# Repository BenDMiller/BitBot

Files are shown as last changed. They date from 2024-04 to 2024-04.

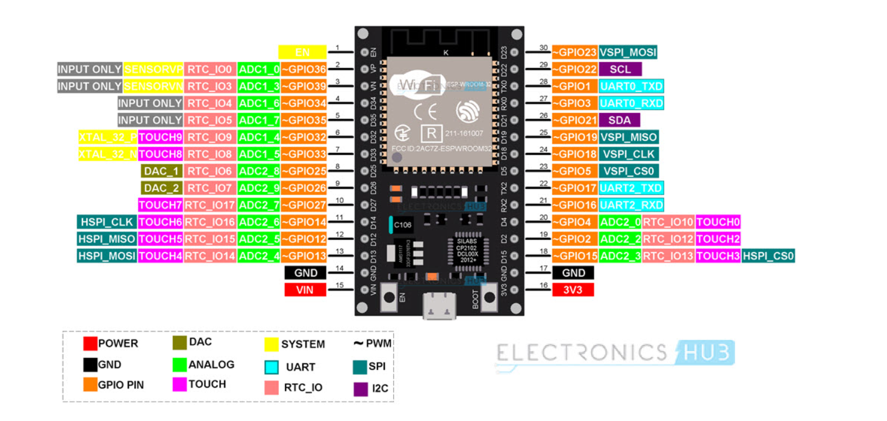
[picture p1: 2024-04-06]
Screenshot 2024-03-08 100537.png

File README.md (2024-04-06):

# Project Description

The BitBot is a simple robotics/embedded systems project that utilized motor control, an accelerometer, and a gyroscope to control the movement of the bot. There are two parts to the robot. There is the main robot body, and the glove controller.

The main body of the robot is a cylinder with two wheels on either side (hence the name, BitBot). The body of the bot, as well as the wheels, were 3D modelled and printed using the Ender3 Creality 3D printer. The chassis for the controller of the bot was also 3D modeled and printed the same way. The controller is attached to a glove, and is used to determine the orientation of your hand in order to control the movement of the BitBot.

A video showing a basic overview can be found [here](https://youtu.be/PNtvKN4nRBg).

Included in the Github Repoistory, there is simple documentation that can be referenced for questions. If more is desired, reach out and that can be updated.

# DISCLAIMER

Not all of the wiring has been completely updated. The documentation provided has some schematics, and they mostly match the proper circuitry, but there are a few changes. If there is difficulty determining the proper circuit design using the designated parts provided, reach out and that can be updated.

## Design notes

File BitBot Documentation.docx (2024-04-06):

# BitBot Robotic Project

# Project Description

The BitBot is a simple robotics/embedded systems project that utilized motor control, an accelerometer, and a gyroscope to control the movement of the bot. There are two parts to the robot. There is the main robot body, and the glove controller.

The main body of the robot is a cylinder with two wheels on either side (hence the name, BitBot). The body of the bot, as well as the wheels, were 3D modelled and printed using the Ender3 Creality 3D printer. The chassis for the controller of the bot was also 3D modeled and printed the same way. The controller is attached to a glove, and is used to determine the orientation of your hand in order to control the movement of the BitBot.

## Parts

- ESP32 WROOM DevKit (https://www.amazon.com/dp/B08D5ZD528?psc=1&ref=ppx_yo2ov_dt_b_product_details) x2
- Wires
- Solder
- Miscellaneous 3D printed parts

Controller:

- MPU6050 3 Axis Accelerometer Gyroscope Module (https://www.amazon.com/dp/B00LP25V1A?ref=ppx_yo2ov_dt_b_product_details&th=1) x1
- Adafruit Powerboost 500c (https://www.amazon.com/dp/B00PY2YTVU?psc=1&ref=ppx_yo2ov_dt_b_product_details) x1
- Slide Switch (https://www.amazon.com/dp/B09R434VJQ?ref=ppx_yo2ov_dt_b_product_details&th=1) x1
- 3.7V 700mAh Lipo Battery (https://www.amazon.com/dp/B07TS8N25G?psc=1&ref=ppx_yo2ov_dt_b_product_details) x1
- Prototype PCB (4cmx6cm) (https://www.amazon.com/dp/B07NM68FXK?psc=1&ref=ppx_yo2ov_dt_b_product_details) x1
- Glove (https://www.amazon.com/dp/B07HG6VMQ9?ref=ppx_yo2ov_dt_b_product_details&th=1&psc=1) x1

Bot:

- 12V 1000RPM DC Motor (https://www.amazon.com/dp/B0745YDSJS?psc=1&ref=ppx_yo2ov_dt_b_product_details) x2
- L298N Motor Driver (https://www.amazon.com/dp/B07WS89781?ref=ppx_yo2ov_dt_b_product_details&th=1) x1
- Boat Rocker Switch (https://www.amazon.com/dp/B0BCJXJZZ7?ref=ppx_yo2ov_dt_b_product_details&th=1) x1
- 12V 2400mAh Li-Ion Battery (https://www.amazon.com/dp/B0C241NS29?ref=ppx_yo2ov_dt_b_product_details&th=1) x1
- Rubber strips for wheel treads (https://www.amazon.com/dp/B08Y7NJJ5C?ref=ppx_yo2ov_dt_b_product_details&th=1)
- M3x0.5 Bolts x6

# Basic Design

The BitBot consists of the main body, as well as the controller. Both require housing and circuitry. Diagrams for both of these can be found below.

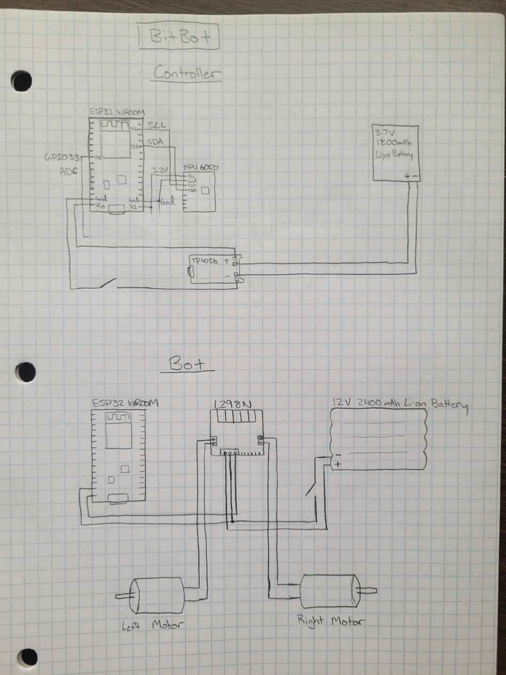
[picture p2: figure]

Figure 1: Basic Circuit Diagrams (control wires for bot not shown)

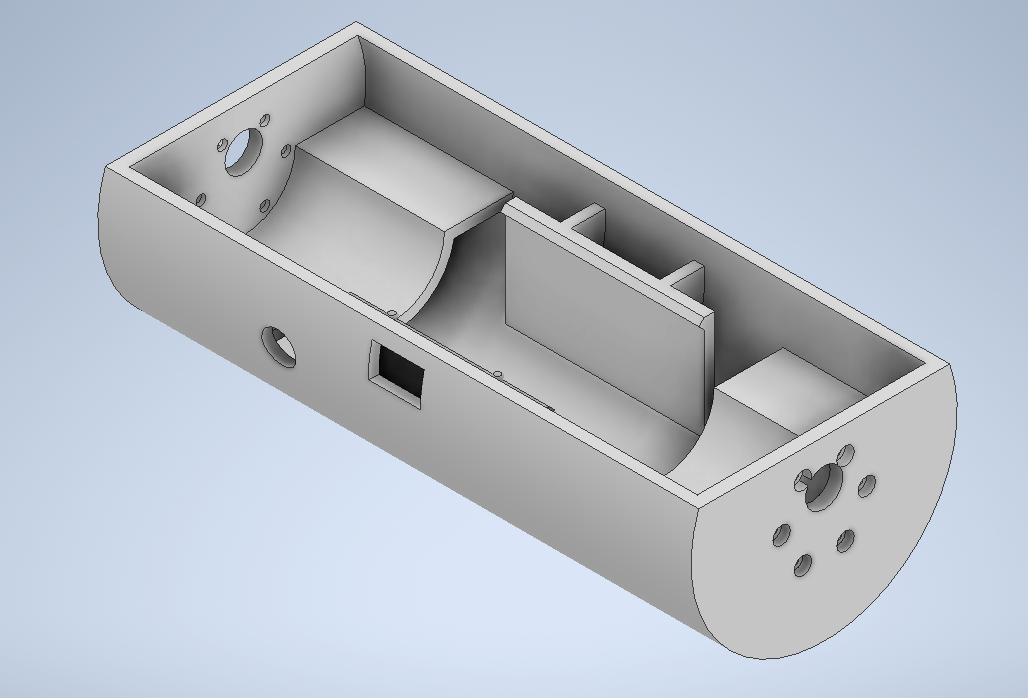
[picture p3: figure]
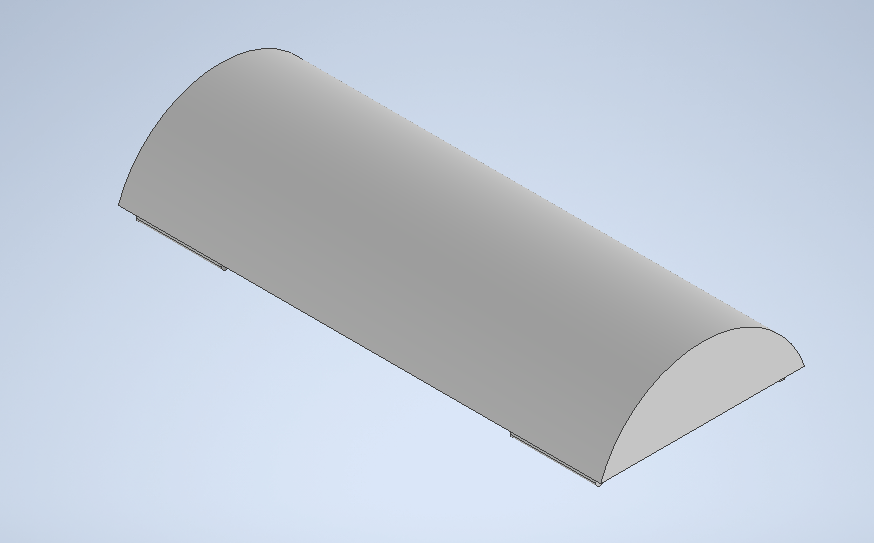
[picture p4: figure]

Figure 2: BitBot Bottom Body Figure 3: BitBot Top Body

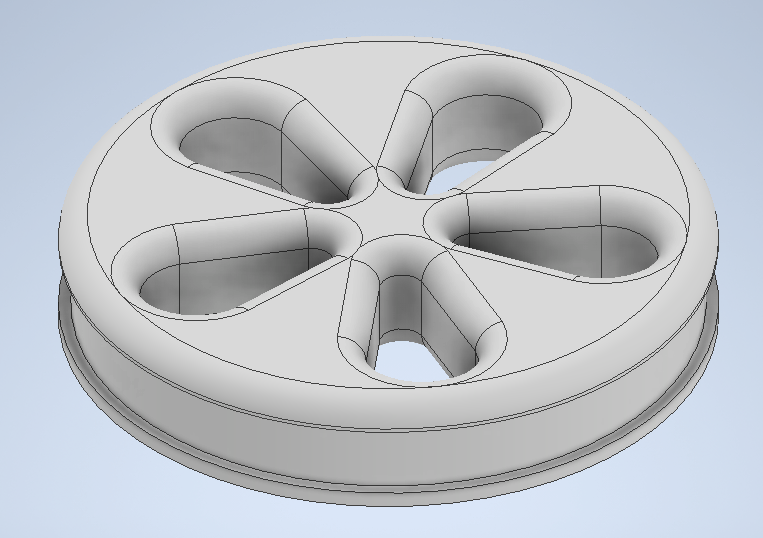
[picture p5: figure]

Figure 4: BitBot Wheel

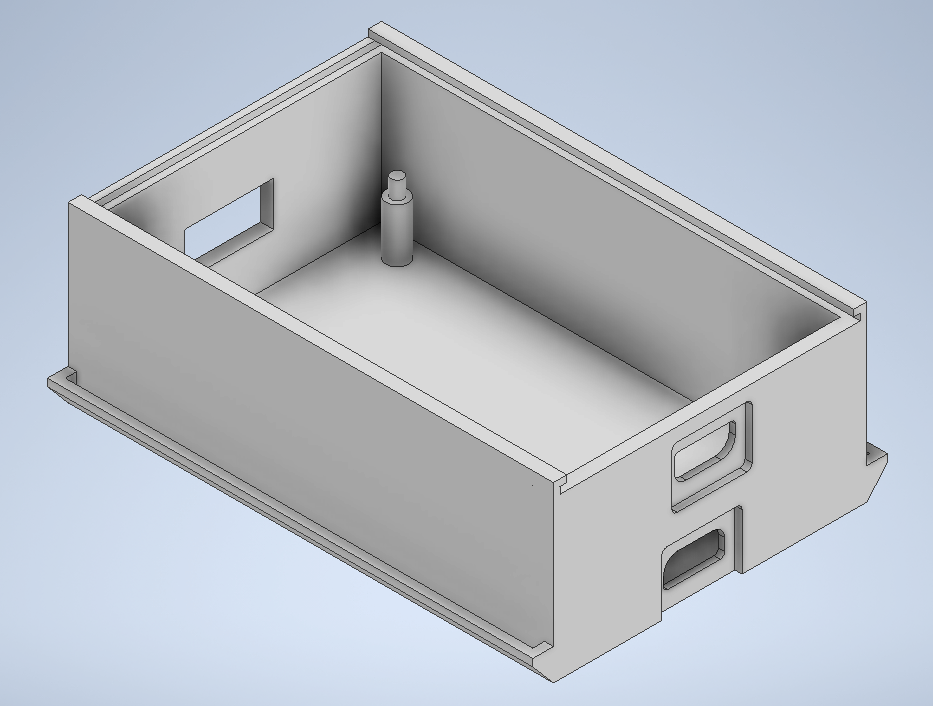
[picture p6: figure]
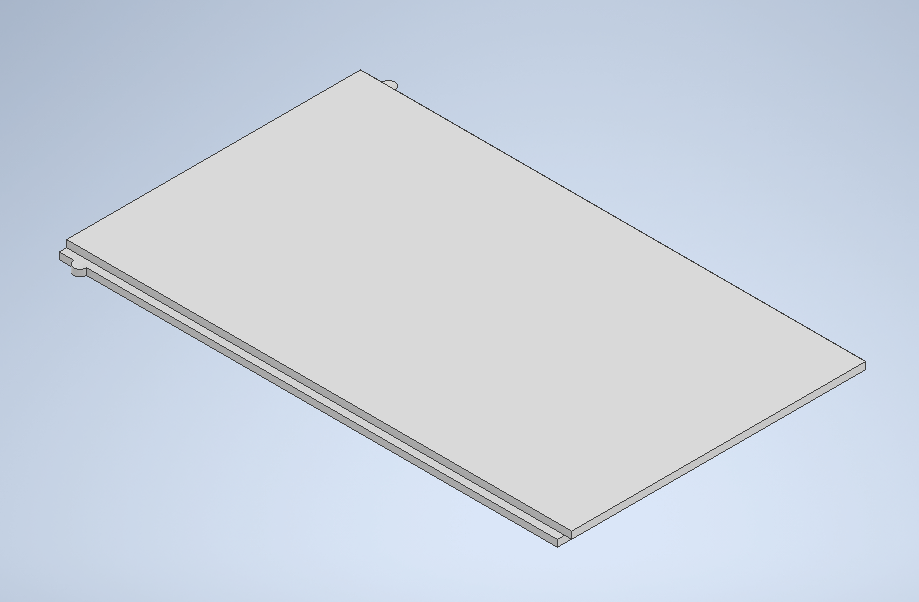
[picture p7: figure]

Figure 5: Controller Chassis Figure 6: Controller Lid

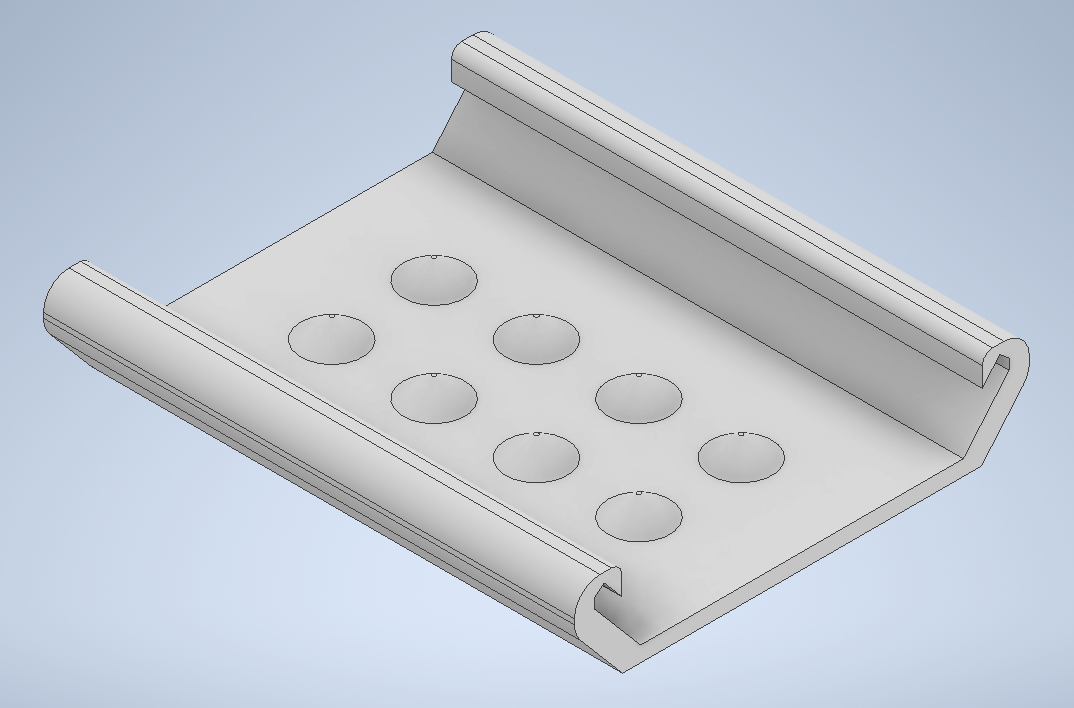
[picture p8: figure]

Figure 7: Controller Glove Clamp

The assembly is simple. The top of the BitBot body snaps into place on the BitBot Bottom Body. It may take some effort to get it in place, but it will go. Then, two wheels are used and attached to the shafts of each of the motors. The motors are attached to the body of the bot using the M3 bolts. After the parts are all put into the body, it will look like the image shown in Figure 8.

The controller is soldered together, and is placed into the Controller Chassis, which is used to house the controller’s system. The lid is slid over, and then that housing can be clamped to the archery glove, connecting the controller to the glove and allowing us to wear the glove and control the robot.

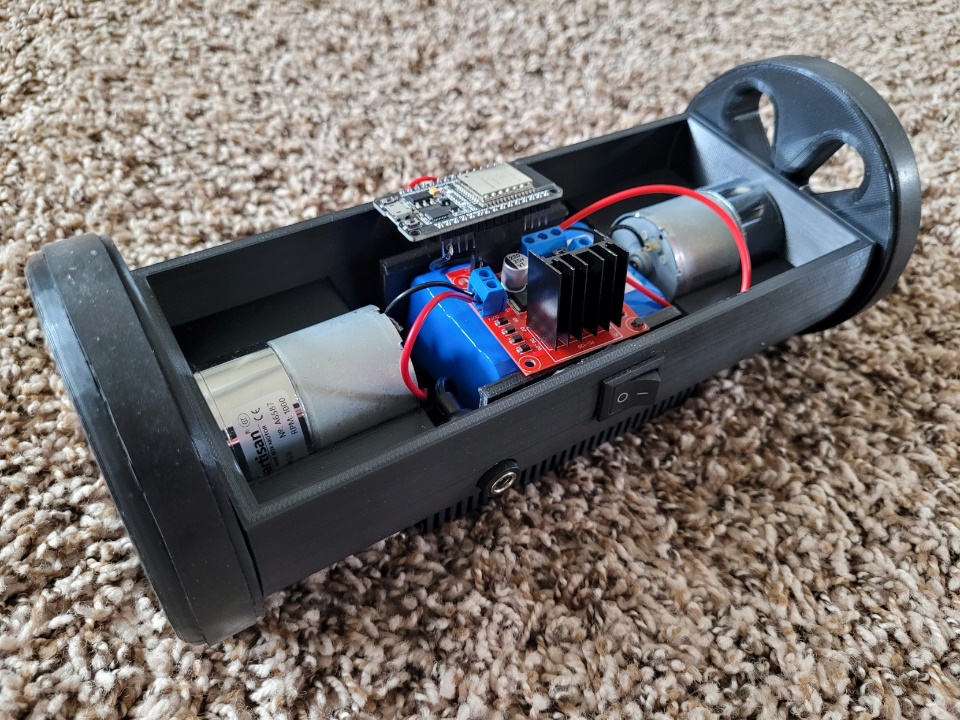
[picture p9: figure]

Figure 8: Completed BitBot without top

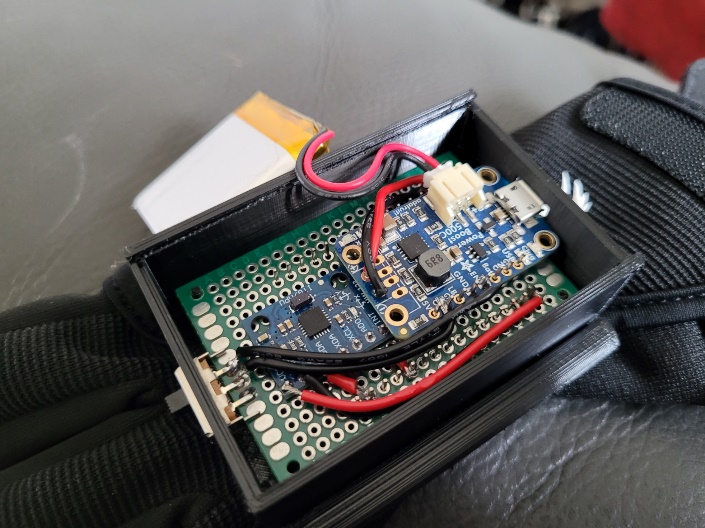
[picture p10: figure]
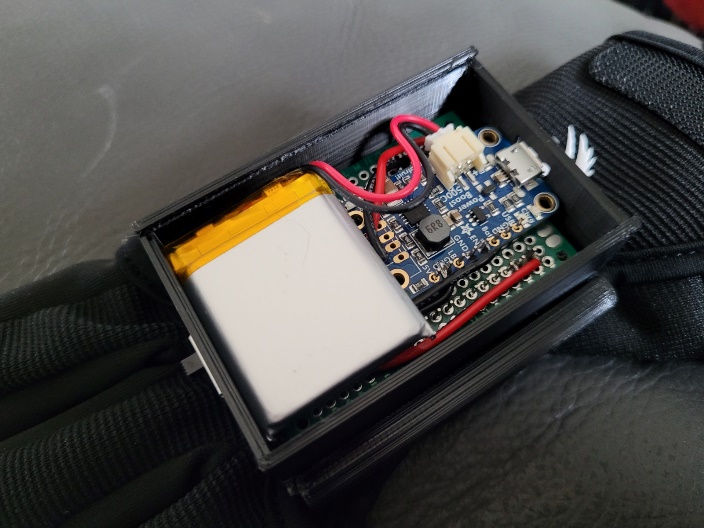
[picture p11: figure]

Figures 9 & 10: Controller circuit in housing, ESP32 soldered on bottom

The code for each of the boards can be uploaded either before or after the boards are soldered and put into their respective housings, though the actual bot’s ESP32 should be programmed before the top of the BitBot is put on. Then, both systems can be turned on, and after about 10 seconds of waiting, all calibration should be done, and the bot will connect to the controller, allowing you to use the motion of your hand to control the bot.

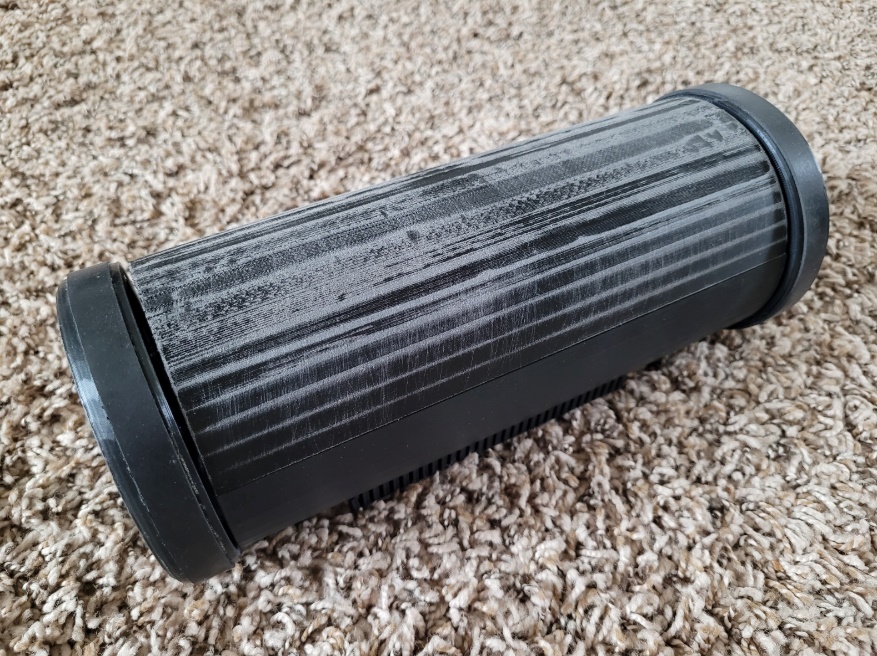
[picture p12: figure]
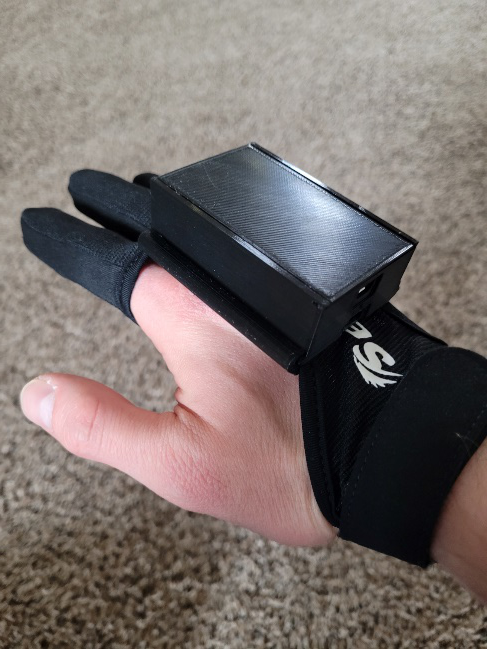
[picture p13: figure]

Figure 11: Completed BitBot Figure 12: Controller on Hand

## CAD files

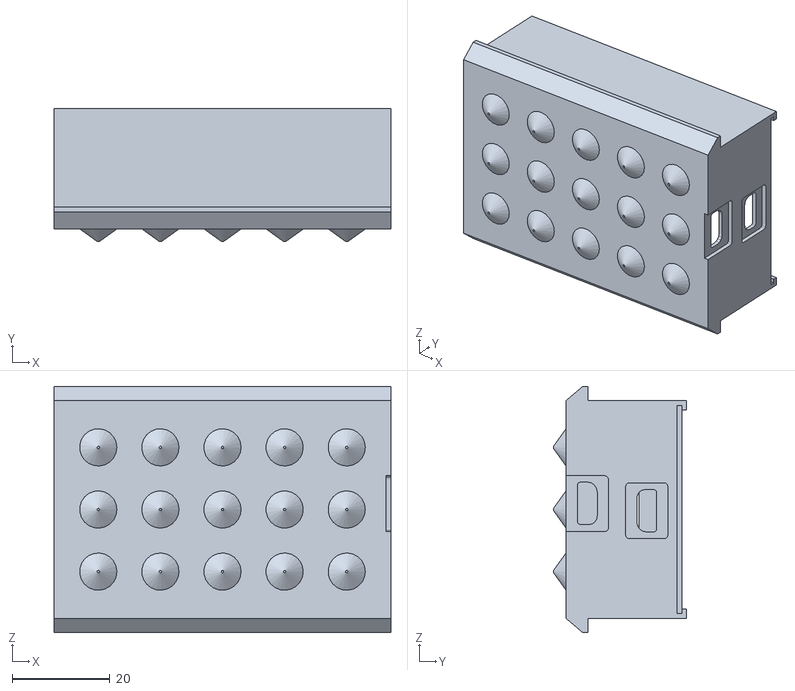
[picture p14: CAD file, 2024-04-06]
ControllerChassis.stl
68.9 x 27.2 x 50.3

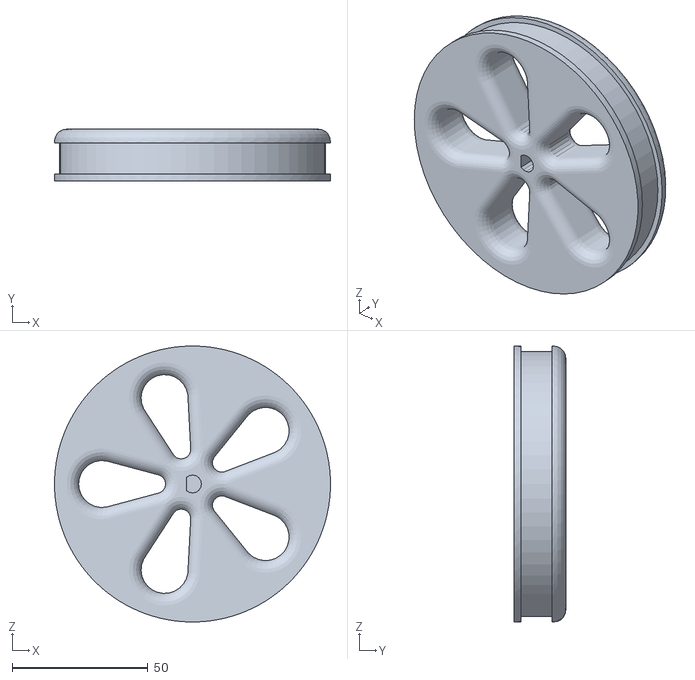
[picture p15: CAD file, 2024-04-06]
BitBotWheel.stl
101.6 x 19.0 x 101.6

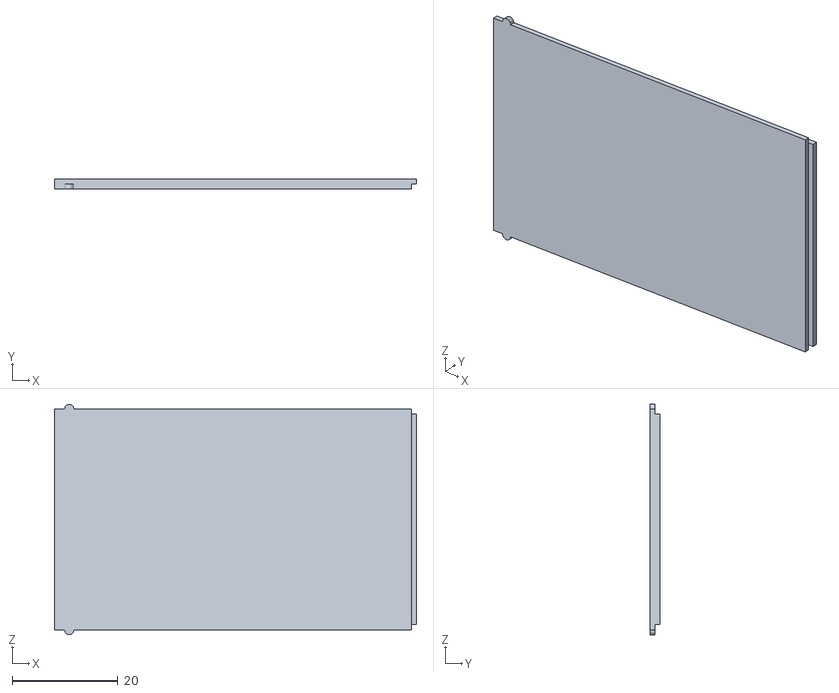
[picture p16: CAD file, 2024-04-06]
ControllerLid.stl
68.5 x 1.88 x 43.6

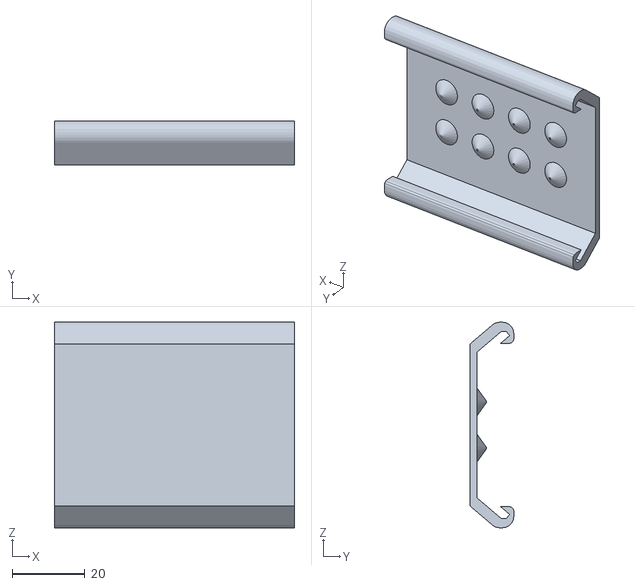
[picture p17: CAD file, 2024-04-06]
ControllerClamp.stl
65.9 x 12.0 x 56.4

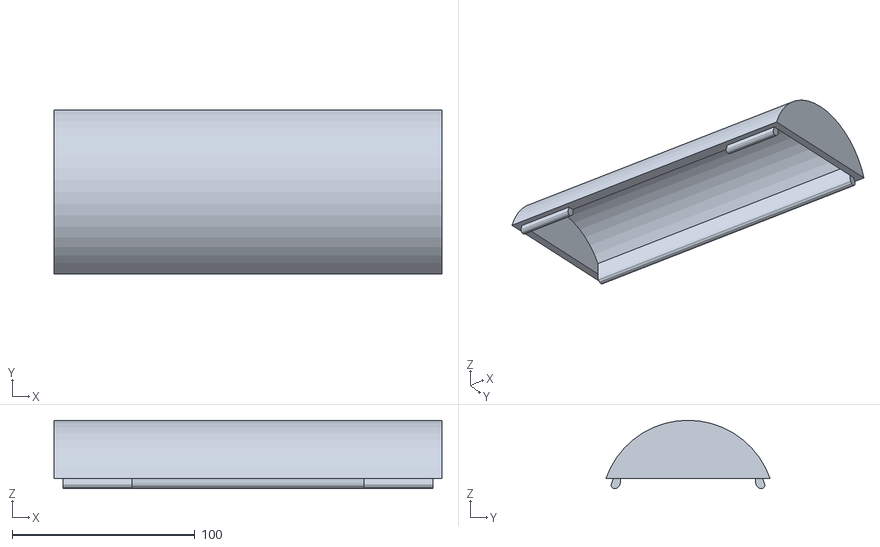
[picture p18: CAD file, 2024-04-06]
BitBotTopBody.stl
212.3 x 89.8 x 37.4

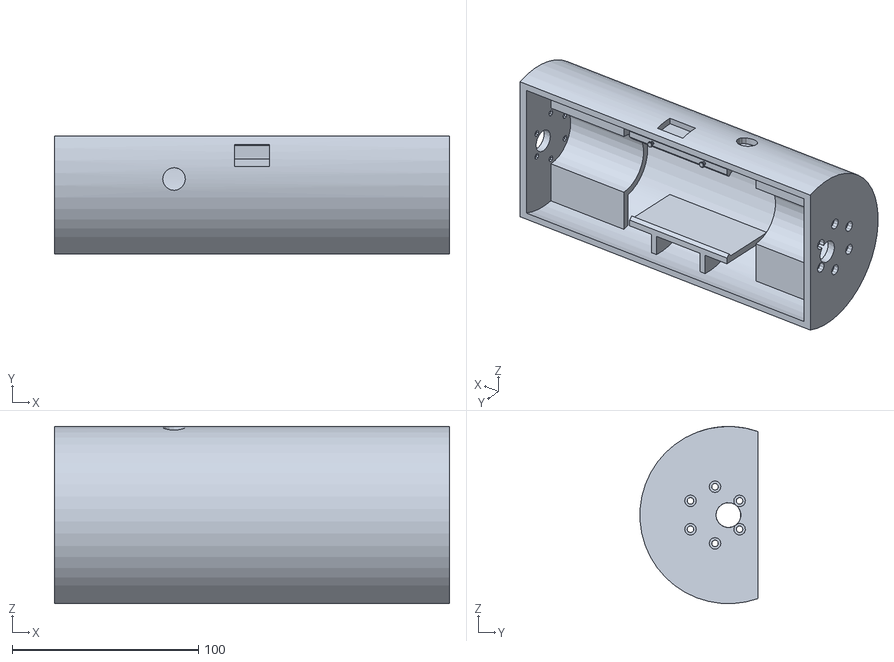
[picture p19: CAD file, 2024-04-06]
BitBotBottomBody.stl
212.3 x 63.4 x 95.2

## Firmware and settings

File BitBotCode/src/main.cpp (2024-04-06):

#include <Arduino.h>
#include "WiFi.h"
#include "ESPAsyncWebServer.h"
#include <WiFi.h>
#include <HTTPClient.h>
#include <Adafruit_MPU6050.h>
#include <Adafruit_Sensor.h>
#include <Wire.h>
#include <iostream>
#include <string>

//Change test strings
String my_code[6] = {"Left Fast", "Right Fast","Both Fast", "Left Slow", "Right Slow", "Both Slow"};
int code_index = 0;

//Gyroscope and Acceleromter Setup
Adafruit_MPU6050 mpu;


// Setting Motor and PWM properties
const int freq = 30000;
const int resolution = 8;
const int leftpwmChannel = 0;
const int rightpwmChannel = 1;
//Duty cycle is between 0-255
int dutyCycleleft = 200;
int dutyCycleright = 200;
const int leftmotorpin1= 17;
const int leftmotorpin2 = 5;
const int leftmotorpwm = 16;
int leftmotordirection = 1;
const int rightmotorpin1= 18;
const int rightmotorpin2 = 19;
const int rightmotorpwm = 21;
int rightmotordirection = 1;

int leftdutycycletransmit = 0;
int leftdirectiontransmit = 1;
int rightdutycycletransmit = 0;
int rightdirectiontransmit = 1;


//Wifi communication Setup
//Set your access point network credentials
const char* ssid = "ESP32-Access-Point";
const char* password = "123456789";

const char* serverleftmotordutycycle = "http://192.168.4.1/dutycycleleft";
const char* serverleftmotordirection = "http://192.168.4.1/leftmotordirection";
const char* serverrightmotordutycycle = "http://192.168.4.1/dutycycleright";
const char* serverrightmotordirection = "http://192.168.4.1/rightmotordirection";

unsigned long previousMillis = 0;
unsigned long previousTime = 0;
const long interval = 5000; 
float AccX;
float AccY;
float AccZ;
float GyroX;
float GyroY;
float GyroZ;
float GyroXDelta;
float GyroYDelta;
float GyroZDelta;
float GyroAngleRoll = 0;
float GyroAnglePitch = 0;
float GyroXCallibrate = 0;
float GyroYCallibrate = 0;
float GyroZCallibrate = 0;
int CalibrateCount;
float AccAngleRoll;
float AccAnglePitch;
float ComplimentaryRoll = 0;
float ComplimentaryPitch = 0;

// Create AsyncWebServer object on port 80
AsyncWebServer server(80);

//General Constants and Variables
const char* System = "Controller";
// const char* System = "Bot";

String leftdutycycle;
String leftdirection;
String rightdutycycle;
String rightdirection;

//Get string from Wifi communiation
String httpGETRequest(const char* serverName) {
  WiFiClient client;
  HTTPClient http;
    
  // Your Domain name with URL path or IP address with path
  http.begin(client, serverName);
  
  // Send HTTP POST request
  int httpResponseCode = http.GET();
  
  String payload = "--"; 
  
  if (httpResponseCode>0) {
    Serial.print("HTTP Response code: ");
    Serial.println(httpResponseCode);
    payload = http.getString();
  }
  else {
    Serial.print("Error code: ");
    Serial.println(httpResponseCode);
  }
  // Free resources
  http.end();

  return payload;
}

void connectToServer(){
  WiFi.begin(ssid, password);
  Serial.println("Connecting");
  while(WiFi.status() != WL_CONNECTED) { 
    delay(500);
    Serial.print(".");
  }
  Serial.println("");
  Serial.print("Connected to WiFi network with IP Address: ");
  Serial.println(WiFi.localIP());
}

void setup() {
  // Serial port for debugging purposes
  Serial.begin(115200);
  
  if(System == "Controller"){
    //MPU Sensor
    Serial.println();
    // Try to initialize!
    if (!mpu.begin()) {
      Serial.println("Failed to find MPU6050 chip");
      while (1) {
        delay(10);
      }
    }
    Serial.println("MPU6050 Found!");

    mpu.setAccelerometerRange(MPU6050_RANGE_8_G);
    Serial.print("Accelerometer range set to: ");
    switch (mpu.getAccelerometerRange()) {
    case MPU6050_RANGE_2_G:
      Serial.println("+-2G");
      break;
    case MPU6050_RANGE_4_G:
      Serial.println("+-4G");
      break;
    case MPU6050_RANGE_8_G:
      Serial.println("+-8G");
      break;
    case MPU6050_RANGE_16_G:
      Serial.println("+-16G");
      break;
    }
    mpu.setGyroRange(MPU6050_RANGE_500_DEG);
    Serial.print("Gyro range set to: ");
    switch (mpu.getGyroRange()) {
    case MPU6050_RANGE_250_DEG:
      Serial.println("+- 250 deg/s");
      break;
    case MPU6050_RANGE_500_DEG:
      Serial.println("+- 500 deg/s");
      break;
    case MPU6050_RANGE_1000_DEG:
      Serial.println("+- 1000 deg/s");
      break;
    case MPU6050_RANGE_2000_DEG:
      Serial.println("+- 2000 deg/s");
      break;
    }

    mpu.setFilterBandwidth(MPU6050_BAND_5_HZ);
    Serial.print("Filter bandwidth set to: ");
    switch (mpu.getFilterBandwidth()) {
    case MPU6050_BAND_260_HZ:
      Serial.println("260 Hz");
      break;
    case MPU6050_BAND_184_HZ:
      Serial.println("184 Hz");
      break;
    case MPU6050_BAND_94_HZ:
      Serial.println("94 Hz");
      break;
    case MPU6050_BAND_44_HZ:
      Serial.println("44 Hz");
      break;
    case MPU6050_BAND_21_HZ:
      Serial.println("21 Hz");
      break;
    case MPU6050_BAND_10_HZ:
      Serial.println("10 Hz");
      break;
    case MPU6050_BAND_5_HZ:
      Serial.println("5 Hz");
      break;
    }
    delay(1000);

    for (CalibrateCount=0; CalibrateCount<2000; CalibrateCount++){
      sensors_event_t a, g, temp;
      mpu.getEvent(&a, &g, &temp);
      GyroXCallibrate += g.gyro.x;
      GyroYCallibrate += g.gyro.y;
      GyroZCallibrate += g.gyro.z;
      delay(1);
    }
      GyroXCallibrate /= 2000;
      GyroYCallibrate /= 2000;
      GyroZCallibrate /= 2000;

    // Setting the ESP as an access point
    Serial.print("Setting AP (Access Point)…");
    // Remove the password parameter, if you want the AP (Access Point) to be open
    WiFi.softAP(ssid, password);

    IPAddress IP = WiFi.softAPIP();
    Serial.print("AP IP address: ");
    Serial.println(IP);
    
    server.on("/dutycycleleft", HTTP_GET, [](AsyncWebServerRequest *request){
      request->send_P(200, "text/plain", String(leftdutycycletransmit).c_str());
      });
    server.on("/dutycycleright", HTTP_GET, [](AsyncWebServerRequest *request){
      request->send_P(200, "text/plain", String(rightdutycycletransmit).c_str());
      });
    server.on("/leftmotordirection", HTTP_GET, [](AsyncWebServerRequest *request){
      request->send_P(200, "text/plain", String(leftdirectiontransmit).c_str());
      });
    server.on("/rightmotordirection", HTTP_GET, [](AsyncWebServerRequest *request){
      request->send_P(200, "text/plain", String(rightdirectiontransmit).c_str());
      });

  // Start server
  server.begin();
  }
  else if(System == "Bot"){
    // sets the pins as outputs:
    pinMode(leftmotorpin1, OUTPUT);
    pinMode(leftmotorpin2, OUTPUT);
    pinMode(leftmotorpwm, OUTPUT);
    pinMode(rightmotorpin1, OUTPUT);
    pinMode(rightmotorpin2, OUTPUT);
    pinMode(rightmotorpwm, OUTPUT);
    // configure LED PWM functionalitites
    ledcSetup(leftpwmChannel, freq, resolution);
    ledcSetup(rightpwmChannel, freq, resolution);
    // attach the channel to the GPIO to be controlled
    ledcAttachPin(leftmotorpwm, leftpwmChannel); 
    ledcAttachPin(rightmotorpwm, rightpwmChannel); 
    //Connect to Server
    connectToServer();
  }
}

void loop() {
  //Controller Code
  float time;
  if(System == "Controller"){
    //Change test data
    unsigned long currentTime = millis();
    // unsigned long currentMillis = millis();
    // if(currentMillis - previousMillis >= interval) {
    //   leftdutycycletransmit = (leftdutycycletransmit + 1)%125 + 130;
    //   rightdutycycletransmit = (rightdutycycletransmit + 1)%125 + 130;
    //   previousMillis = currentMillis;
    // }
  
    //MPU Sensor
    sensors_event_t a, g, temp;
    mpu.getEvent(&a, &g, &temp);

    time = currentTime-previousTime;
    AccX = a.acceleration.x/9.8 - 0.04;
    AccY = a.acceleration.y/9.8 + 0.01;
    AccZ = a.acceleration.z/9.8 + 0.04;
    GyroX = g.gyro.x - GyroXCallibrate;
    GyroY = g.gyro.y - GyroYCallibrate;
    GyroZ = g.gyro.z - GyroZCallibrate;
    GyroXDelta = GyroX*time/(PI/180)/1000;
    GyroYDelta = GyroY*time/(PI/180)/1000;
    GyroZDelta = GyroZ*time/(PI/180)/1000;
    
    AccAngleRoll = -atan(AccY/sqrt(pow(AccX, 2) + pow(AccZ, 2)))/(PI/180);
    AccAnglePitch = -atan(AccX/sqrt(pow(AccY, 2)+ pow(AccZ, 2)))/(PI/180);
    GyroAngleRoll = GyroAngleRoll - GyroX*time/(PI/180)/1000;
    GyroAnglePitch = GyroAnglePitch + GyroY*time/(PI/180)/1000;

    ComplimentaryRoll = ((ComplimentaryRoll-GyroXDelta)*0.98) + (0.02*AccAngleRoll);
    ComplimentaryPitch = ((ComplimentaryPitch-GyroYDelta)*0.98) + (0.02*AccAnglePitch);

    // int leftwheel = (pow(ComplimentaryRoll,3))/pow(60,2) + (ComplimentaryPitch*0.2)*((ComplimentaryRoll)/abs(ComplimentaryRoll));
    // int rightwheel = (pow(ComplimentaryRoll,3))/pow(60,2) + (-ComplimentaryPitch*0.2)*((ComplimentaryRoll)/abs(ComplimentaryRoll));
    
    int leftwheel;
    int rightwheel;
    // if(ComplimentaryPitch >= 0){
    //   leftwheel = (pow(ComplimentaryRoll,3))/pow(60,2) + (30/(1+pow(M_E, (-0.15*ComplimentaryPitch+5))))*((ComplimentaryRoll)/abs(ComplimentaryRoll));
    //   rightwheel = (pow(ComplimentaryRoll,3))/pow(60,2) + (-30/(1+pow(M_E, (-0.15*ComplimentaryPitch+5))))*((ComplimentaryRoll)/abs(ComplimentaryRoll));
    // }
    // else{
    //   leftwheel = (pow(ComplimentaryRoll,3))/pow(60,2) + (30/(1+pow(M_E, (-0.15*ComplimentaryPitch-5)))-30)*((ComplimentaryRoll)/abs(ComplimentaryRoll));
    //   rightwheel = (pow(ComplimentaryRoll,3))/pow(60,2) + (-(30/(1+pow(M_E, (-0.15*ComplimentaryPitch-5)))-30))*((ComplimentaryRoll)/abs(ComplimentaryRoll));
    // }
    if(ComplimentaryPitch >= 0){
      leftwheel = ComplimentaryRoll + (15/(1+pow(M_E, (-0.25*ComplimentaryPitch+5))))*((ComplimentaryRoll)/abs(ComplimentaryRoll));
      rightwheel = ComplimentaryRoll + (-15/(1+pow(M_E, (-0.25*ComplimentaryPitch+5))))*((ComplimentaryRoll)/abs(ComplimentaryRoll));
    }
    else{
      leftwheel = ComplimentaryRoll + (15/(1+pow(M_E, (-0.25*ComplimentaryPitch-5)))-30)*((ComplimentaryRoll)/abs(ComplimentaryRoll));
      rightwheel = ComplimentaryRoll + (-(15/(1+pow(M_E, (-0.25*ComplimentaryPitch-5)))-30))*((ComplimentaryRoll)/abs(ComplimentaryRoll));
    }

    leftdutycycletransmit = min<int>((132 + abs(leftwheel)), 190);
    rightdutycycletransmit = min<int>((132 + abs(rightwheel)), 190);

    // leftdutycycletransmit = min<int>((130 + abs(ComplimentaryRoll)-5), 180);
    // rightdutycycletransmit = min<int>((130 - 1 + abs(ComplimentaryRoll)-5), 180);
    leftdirectiontransmit = leftwheel >=0 ? 1:-1;
    rightdirectiontransmit = rightwheel >=0 ? 1:-1;

    Serial.print("ComplimentaryAngleRoll:");
    Serial.print(ComplimentaryRoll);
    Serial.print(",");
    Serial.print("ComplimentaryAnglePitch:");
    Serial.print(ComplimentaryPitch);
    Serial.print(",");
    Serial.print("LeftWheel:");
    Serial.print(leftwheel);
    Serial.print(",");
    Serial.print("RightWheel:");
    Serial.print(rightwheel);
    Serial.print(",");
    Serial.print("LeftDirection:");
    Serial.print(leftdirectiontransmit);
    Serial.print(",");
    Serial.print("RightDirection:");
    Serial.println(rightdirectiontransmit);

    previousTime = currentTime;
    
  }
  //Bot Code
  else if(System == "Bot"){
    //Print Data
    // unsigned long currentMillis = millis();
    // if(currentMillis - previousMillis >= interval) {
      // Check WiFi connection status
      if(WiFi.status()== WL_CONNECTED ){
        leftdutycycle = httpGETRequest(serverleftmotordutycycle);
        leftdirection = httpGETRequest(serverleftmotordirection);
        rightdutycycle = httpGETRequest(serverrightmotordutycycle);
        rightdirection = httpGETRequest(serverrightmotordirection);
        Serial.println("LDC: " + leftdutycycle);
        Serial.println("RDC: " + rightdutycycle);
        // save the last HTTP GET Request
        // previousMillis = currentMillis;
      } 
      else{
        Serial.println("WiFi Disconnected");
        ledcWrite(leftpwmChannel, 0);
        ledcWrite(rightpwmChannel, 0);
        connectToServer();
      }
    // }

    dutyCycleleft = leftdutycycle.toInt();
    leftmotordirection = leftdirection.toInt();
    dutyCycleright = rightdutycycle.toInt();
    rightmotordirection = rightdirection.toInt();

    if(leftmotordirection == 1){
      digitalWrite(leftmotorpin1, LOW);
      digitalWrite(leftmotorpin2, HIGH);
    }
    else if(leftmotordirection == -1){
      digitalWrite(leftmotorpin1, HIGH);
      digitalWrite(leftmotorpin2, LOW);
    }
    if(rightmotordirection == 1){
      digitalWrite(rightmotorpin1, LOW);
      digitalWrite(rightmotorpin2, HIGH);
    }
    else if(rightmotordirection == -1){
      digitalWrite(rightmotorpin1, HIGH);
      digitalWrite(rightmotorpin2, LOW);
    }
    ledcWrite(leftpwmChannel, dutyCycleleft);
    ledcWrite(rightpwmChannel, dutyCycleright);
  }
}
